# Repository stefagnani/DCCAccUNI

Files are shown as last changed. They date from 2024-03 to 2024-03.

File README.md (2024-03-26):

# DCCAccUNI
Decoder DCC accessori universale. Più versioni basati su hardware di base simile per più funzioni

DECODER ACCESSORI UNIVERSALE

Basato su Software e hardware di MERG
https://www.merg.org.uk/resources/dcc_download

Il presente progetto illustra la realizzazione di un decoder DCC accesori per pilotare in alternativa 4 motori lenti (tipo Tortoise Conrad, o KATO)  4 motori elettromeganertici oppure otto luci generiche per illuminazione o segnali.

Basato sul software originale di MERG versione ACC5, permette un funzionamento toggle standard come da specifiche DCC, ovvero un unico indirizzo pilota 4 coppie di comandi (due per scambio), oppure può essere configurato per operare singolarmente ogni uscita.

Il progetto comprende N Assy (versioni hardware) delle schede in funzione del tipo di accessori da pilotare. Ad oggi sono previste tre tipologie di Assy:

ASSY #260324             Hardware per pilotare 4 motori elettromagnetici
ASSY#XXXXX		Hardware per pilotare segnali 
ASSY#XXXXX		Harware per pilotare motori lenti di tpo Totroise, KATO ecc.

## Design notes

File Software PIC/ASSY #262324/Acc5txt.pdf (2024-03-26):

MERG DCC accessory decoder – Firmware version 5 (ACC5)

The firmware version (ACC4) runs either the Pulse decoder (with inbuilt CDU) or the ‘steady state’ decoder with DC outputs. It is compatible with both the MERG accessory encoder and commercial systems like Lenz. However, both of these assume that the decoder will be used to drive point motors with the outputs operating in pairs. Hence it is not possible to activate the 8 outputs individually as either one side or the other of a ‘pair’ is always active. Also, Lenz systems do not send ‘deactivate’ commands so an output cannot be turned off and it is assumed that activating one output of a pair will automatically turn off the other side. This must be a property of the decoder and ACC4 had the ‘toggle’ mode introduced for this purpose. (The MERG encoder does send ‘deactivate’ commands).

From its early stages, the MERG accessory decoders had the capability to operate all 8 outputs independently but this could not be achieved with command stations assuming ‘paired’ operation.

ACC5 now has an option which allows a single decoder board to act as two separate decoders. In this ‘dual’ mode, outputs 1 to 4 are controlled by one decoder address and outputs 5 to 8 are controlled by a different address. This enables a single decoder board to have all 8 outputs individually controlled by systems that assume paired operation. Activating side ‘b’ of an output will turn that output on. Activating side ‘a’ of that output will turn it off so each decoder ‘address’ works 4 outputs.

For ACC5, an activate to point 1 (001) will turn output 1 on and an activate to point 0 (000) will turn output 1 off. When used with the MERG encoder, this means the output is on when the matrix switch is open and off when the switch is closed. This arrangement was to maintain Lenz compatibility where a ‘+’ will turn output 1 on and a ‘-‘ will turn it off. With the MERG encoder, 8 individual on/off switches will control the 8 outputs of a single decoder board.

The main purpose of this arrangement is for light or signal operation. The ‘steady state’
MERG decoder board has outputs suited for 12v bulbs or LEDs (resistors on the decoder board). However, the same board could drive 8 points using the Servo4 drivers as these only need an on / off input.

Method of operation

ACC5 can work in either single or dual mode dependent on the setting of bit 7 (the MSB) of CV545 (CV33). As this cannot be set using ‘register’ mode programming, it requires a programmer capable of accessing CV545 or CV33. Either page mode or direct mode are accepted.

To use as ACC4 (single mode) set CV545, bit 7 off. CV545 also contains the ‘toggle’ bits for Lenz system operation. To use in dual mode, set bit 7 of CV545. In this mode, the toggle bits are ignored.

To set the addresses.

Set CV545 bit 7 off. Then program the decoder as usual with address data at CV513 and CV521. CV513 (CV1) contains the low 6 bits of the address. (0 to 63) and CV521 (CV9) contains the high three bits (0 to 7). When in dual mode, this address controls outputs 1 to 4. CV514 (CV2) should be left at 255 so all outputs are active and CVs 515 to 518 set the on time of the outputs. Note, with the present code, CV515 sets the time for outputs 1 and 2, CV516 for 3 and 4 etc. irrespective of mode. This may be modified in future so all 8 outputs can have different times. When operating lights or signals it will be normal to set the timing CVs to 0 so the output is continuous.

Now set CV545 bit 7 to 1. Repeat the address programming for the decoder that will control outputs 5 to 8. Obviously this second address should be different from the first but it doesn’t have to be consecutive and can be higher or lower than the first address.

The decoder is now set up for dual mode. Reading the CVs in this mode will return the values for the second address. You will need to clear CV545 bit 7 to 0 in order to read the CVs for the first address. Clearing this bit also places the decoder in the conventional ‘single’ mode which would be used for points or other applications requiring paired outputs.

The following alternative CV's and register addresses are supported.
NMRA CV | Alt CV Register
CV513 | CV1 | R1 (Address low 6 bits))
CV514 | CV2 | (not available in register mode)
CV515 | CV3 | R2 (F1 on time)
CV516 | CV4 | R3 (F2 on time)
CV517 | CV5 | R4 (F3 on time)
CV518 | CV6 | R5 (F4 on time)
R6 (Page register)
CV519 | CV7 | R7 (version)
CV520 | CV8 | R8 (manufacturer)
CV521 | CV9 | Address high 3 bits (not available in register mode)
CV541 | CV29 Configuration (not available in register mode)
CV545 | CV33 Sets toggle function for Lenz compatibility and dual mode option.
Not available in register mode

No other CVs are supported.

CV545 (CV33) | bit 0 | sets toggle mode for OP1/2
bit 1 | sets toggle mode for OP3/4
bit 2 | sets toggle mode for OP5/6
bit 3 | sets toggle mode for OP7/8
bit 7 | sets dual decoder mode

Note: The toggle is for Lenz compatibility in single decoder mode only. These bits are ignored in dual mode. For compatibility with the MERG encoder, they should be set to 0.

The ACC5 code on the MERG website has the default CVs set for dual mode at decoder addresses 1 and 2.

M P Bolton | ACC5txt | Rev 1 | 04/08/05

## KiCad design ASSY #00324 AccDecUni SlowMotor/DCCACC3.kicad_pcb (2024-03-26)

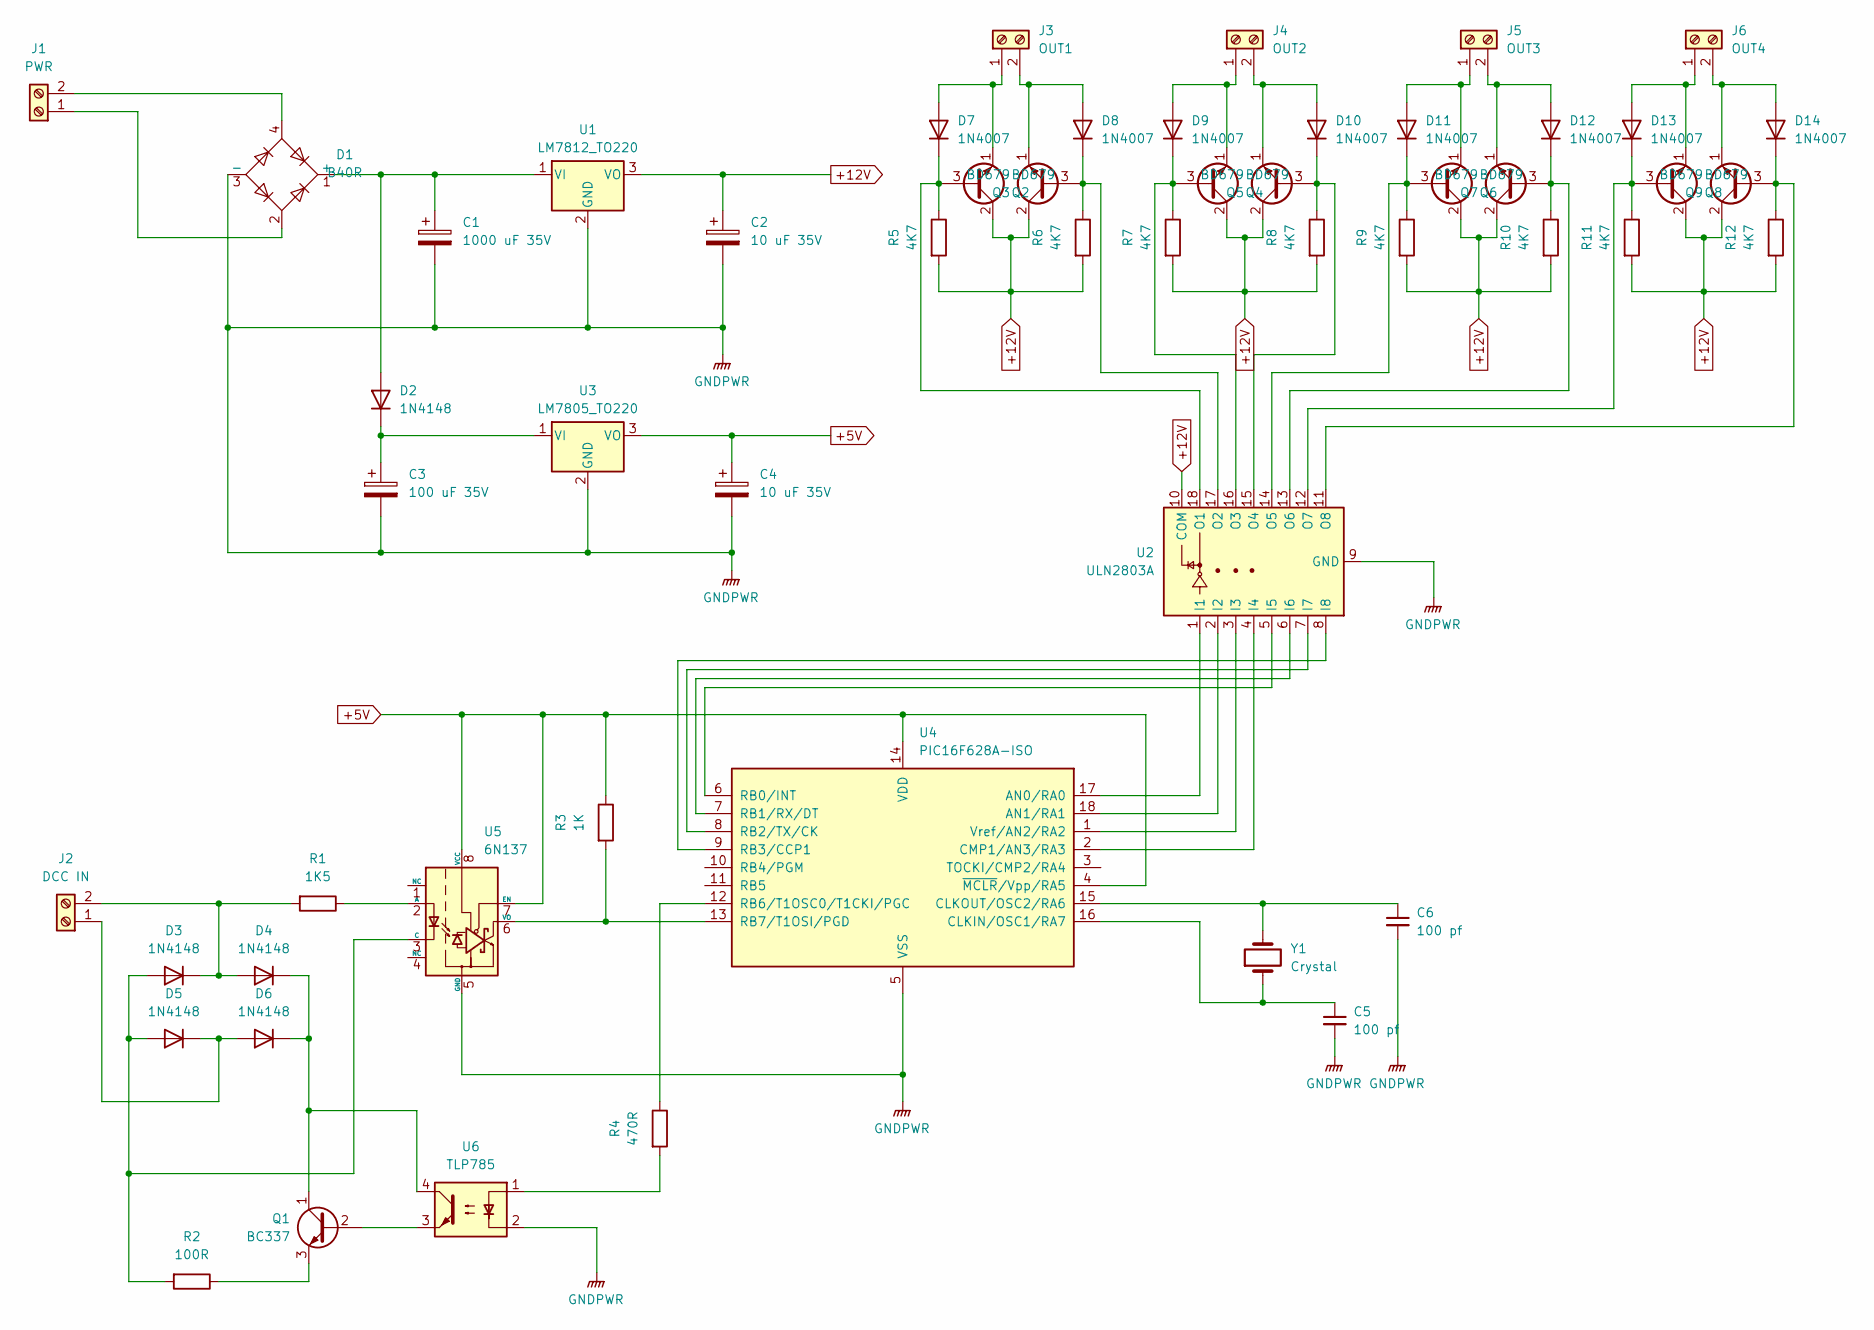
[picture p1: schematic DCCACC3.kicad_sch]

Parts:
C1: 1000 uF 35V; CP_Radial_D16.0mm_P7.50mm
C2, C4: 10 uF 35V; CP_Radial_D5.0mm_P2.50mm
C3: 100 uF 35V; CP_Radial_D10.0mm_P5.00mm
C5, C6: 100 pf; C_Disc_D3.0mm_W2.0mm_P2.50mm
D1: B40R; Diode_Bridge_Round_D9.0mm
D2, D3, D4, D5, D6: 1N4148; D_DO-35_SOD27_P7.62mm_Horizontal
D7, D8, D9, D10, D11, D12, D13, D14: 1N4007; D_DO-41_SOD81_P10.16mm_Horizontal
J1: PWR; mkds_1,5-2
J2: DCC IN; mkds_1,5-2
J3: OUT1; mkds_1,5-2
J4: OUT2; mkds_1,5-2
J5: OUT3; mkds_1,5-2
J6: OUT4; mkds_1,5-2
Q1: BC337; TO-92_Inline
Q2, Q3, Q4, Q5, Q6, Q7, Q8, Q9: BD679; TO-126-3_Vertical
R1: 1K5; R_Axial_DIN0207_L6.3mm_D2.5mm_P7.62mm_Horizontal
R2: 100R; R_Axial_DIN0207_L6.3mm_D2.5mm_P7.62mm_Horizontal
R3: 1K; R_Axial_DIN0207_L6.3mm_D2.5mm_P7.62mm_Horizontal
R4: 470R; R_Axial_DIN0207_L6.3mm_D2.5mm_P7.62mm_Horizontal
R5, R6, R7, R8, R9, R10, R11, R12: 4K7; R_Axial_DIN0207_L6.3mm_D2.5mm_P7.62mm_Horizontal
U1: LM7812_TO220; TO-220-3_Vertical
U2: ULN2803A; DIP-18_W7.62mm
U3: LM7805_TO220; TO-220-3_Vertical
U4: PIC16F628A-ISO; DIP-18_W7.62mm
U5: 6N137; DIP-8_W7.62mm
U6: TLP785; DIP-4_W7.62mm
Y1: Crystal; Crystal_HC18-U_Vertical

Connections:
+5V: C4.1, R3.1, U3.3 (VO), U4.4 (~MCLR/Vpp/RA5), U4.14 (VDD), U5.7 (EN), U5.8 (VCC)
+12V: C2.1, Q2.2 (C), Q3.2 (C), Q4.2 (C), Q5.2 (C), Q6.2 (C), Q7.2 (C), Q8.2 (C), Q9.2 (C), R5.2, R6.2, R7.2, R8.2, R9.2, R10.2, R11.2, R12.2, U1.3 (VO), U2.10 (COM)
GNDPWR: C1.2, C2.2, C3.2, C4.2, C5.2, C6.2, D1.3 (-), U1.2 (GND), U2.9 (GND), U3.2 (GND), U4.5 (VSS), U5.5 (GND), U6.2
unnamed: C1.1, D1.1 (+), D2.2 (A), U1.1 (VI)
unnamed: C3.1, D2.1 (K), U3.1 (VI)
unnamed: D3.2 (A), D5.2 (A), R2.2, U5.3 (C)
unnamed: D3.1 (K), D4.2 (A), J2.2, R1.2
unnamed: D4.1 (K), D6.1 (K), Q1.1 (C), U6.4
unnamed: D5.1 (K), D6.2 (A), J2.1
unnamed: D7.2 (A), J3.1, Q2.1 (E)
unnamed: D7.1 (K), Q2.3 (B), R5.1, U2.18 (O1)
unnamed: D8.2 (A), J3.2, Q3.1 (E)
unnamed: D8.1 (K), Q3.3 (B), R6.1, U2.17 (O2)
unnamed: D9.2 (A), J4.1, Q4.1 (E)
unnamed: D9.1 (K), Q4.3 (B), R7.1, U2.16 (O3)
unnamed: D10.2 (A), J4.2, Q5.1 (E)
unnamed: D10.1 (K), Q5.3 (B), R8.1, U2.15 (O4)
unnamed: D11.2 (A), J5.1, Q6.1 (E)
unnamed: D11.1 (K), Q6.3 (B), R9.1, U2.14 (O5)
unnamed: D12.2 (A), J5.2, Q7.1 (E)
unnamed: D12.1 (K), Q7.3 (B), R10.1, U2.13 (O6)
unnamed: D13.2 (A), J6.1, Q8.1 (E)
unnamed: D13.1 (K), Q8.3 (B), R11.1, U2.12 (O7)
unnamed: D14.2 (A), J6.2, Q9.1 (E)
unnamed: D14.1 (K), Q9.3 (B), R12.1, U2.11 (O8)
unnamed: D1.2, J1.1
unnamed: D1.4, J1.2
unnamed: Q1.2 (B), U6.3
unnamed: Q1.3 (E), R2.1
unnamed: R4.2, U6.1
unnamed: U2.1 (I1), U4.17 (AN0/RA0)
unnamed: U2.2 (I2), U4.18 (AN1/RA1)
unnamed: U2.3 (I3), U4.1 (Vref/AN2/RA2)
unnamed: U2.4 (I4), U4.2 (CMP1/AN3/RA3)
unnamed: U2.5 (I5), U4.6 (RB0/INT)
unnamed: U2.6 (I6), U4.7 (RB1/RX/DT)
unnamed: U2.7 (I7), U4.8 (RB2/TX/CK)
unnamed: U2.8 (I8), U4.9 (RB3/CCP1)
unnamed: C5.1, U4.16 (CLKIN/OSC1/RA7), Y1.1
unnamed: C6.1, U4.15 (CLKOUT/OSC2/RA6), Y1.2
unnamed: R4.1, U4.12 (RB6/T1OSC0/T1CKI/PGC)
unnamed: R3.2, U4.13 (RB7/T1OSI/PGD), U5.6 (VO)
unnamed: R1.1, U5.2 (A)

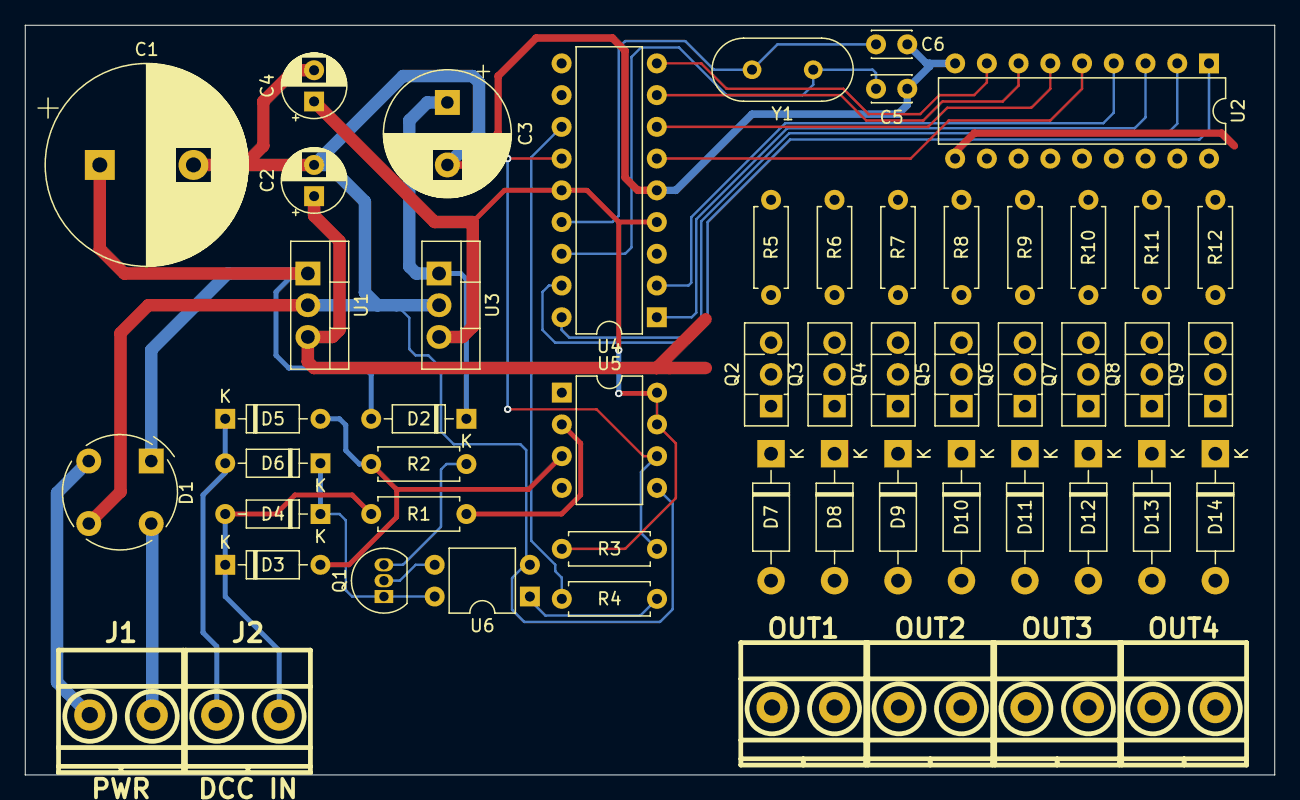
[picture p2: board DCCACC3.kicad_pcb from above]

Board: 2 copper layers, 100.0 x 60.0 mm, 54 parts (0 on the bottom side), 43 nets.

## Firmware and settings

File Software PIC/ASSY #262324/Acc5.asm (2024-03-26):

;*******************************************************************************
;
;	Acc5
;	
;	This is a new version based on Acc4 so that 8 individual outputs can be 
;	controlled as two blocks of 4 at separate addresses. This allows either
;	the MERG encoder or other commercial controllers which expect outputs to
;	only work in pairs to work individual outputs. In this mode, an activate to
;	the first of a pair turns that output on. An activate to the other in a pair
;	turns the first output off. Main purpose is to allow 8 signals / lights from
;	one decoder. Also will operate 8 points via two  MERG Servo4 boards.
;
;	There are two completely separate blocks of CVs so it is effectively two 
;	decoders in one. This dual mode is set by bit 7 of CV545 (CV33)
;
;	If this bit is 0, the decoder operates as a standard Acc4.
;	Tested with MERG encoder in mode 1. 11/05/05. Seems OK
;	Not tested with a Lenz system.
;	Acc5 modified for Lenz system  30/05/05 to reverse the output pairs
;
;	Note:  Default setting is dual mode.
 
;	Accessory decoder based on original loco decoder program by D Probst 
;	to whom full acknowledgement is made.
;
;	First modified for accessory control by Mike Bolton  2nd Dec 1998
;	Revised 25/5/02 for 16F628 PIC
;
;	Program is intended to be used with the accessory decoder designs    	
;	DCCACC2B and DCCACC3. The decoder is opto isolated . No power booster is required 
;	but the signals can be taken from the track if desired. 
;	A separate 20v AC power supply is needed.
;	Decoder includes circuitry to drive solenoid
;	point motors using a capacitor discharge technique. 
;
;	
;
;	Schematic, PCB layout and source listing (+ HEX file) available. Contact
;	Mike Bolton at mbolton@fs1.with.man.ac.uk.
;
;	Details of a matching accessory encoders are also available.
;
;	
;This is code for a PIC16F628A . This program will read three, four,
;and five byte packets and supports paged, direct CV or register mode 
;access of CV data. Direct read uses bit mode. Direct write uses both
;byte write or bit manipulation.
;
;
;The decoder follows the NMRA standard for an Accessory Decoder. It controls
;four pairs of outputs with on times set by the CVs in increments of 
;10 millisecs. Range is 10 ms to 2.54 sec.or continuous.
;
;Supports 9 bit addressing. (3 byte packets) at present.

;The processor is configured to operate at 8MHz. 
;When programming,the fuses should be set with HS clock, WDT On.
;

;The following NMRA defined CV's and ranges are supported...

;NMRA  alt
;CV513 (1)  Lower 6 address bits    00h - 3Fh  
;CV514 (2) Auxiliary activation    00h - FFh  Bits 0 to 7.Each bit sets an output.
;					   1 is active, 0 is inactive   
;CV515 F1 function 'on' time   00h - FFh  Time in 10ms steps. 0 is continuous.
;CV516 F2  
;CV517 F3                                        
;CV518 F4
;CV519 Version Number     	00h -FFh   Cannot be changed (same as CV8)
;CV520 Manufacturers ID        00h -FFh   Cannot be changed (same as CV9)
;                
;CV521 Upper 3 bits of		00h -07h
;      	    address     
;CV541 Configuration		Bit 7 = 1  (same as CV29)
;CV545 Mode			Bits 0 to 3 set the toggle mode on output pairs (Lenz compatibility)
;				Bit 7 sets dual mode

; The following alternative CV's and register addresses are supported.
; NMRA CV  Alt CV   Register
; CV513    CV1      R1 (Address)
; CV514    CV2         (not available in register mode)
; CV515    CV3      R2 (F1 on time)
; CV516    CV4      R3 (F2 on time)
; CV517    CV5      R4 (F3 on time)
; CV518    CV6      R5 (F4 on time)
;                   R6 (Page register)
; CV519    CV7      R7 (version)
; CV520    CV8      R8 (manufacturer)
; CV521    CV9         (not available in register mode)
; CV541    CV29        (not available in register mode)
; CV545	   CV33		(sets toggle function for Lenz compatibility)
; 
;	No other CVs are supported.

        processor       16F628A
	include		"p16f628A.inc"
	__CONFIG	h'3F66' ; PUTimer on, WDT on, HS clock, BOD on

				; 8 Mhz Crystal

;Variable definition - I/O Port assignments

;F1a  	equ    	PORTA,0		;pin 17
;F1b	equ		PORTA,1		;pin 18   
;F2a  	equ     PORTA,2		;pin 1
;F2b  	equ    	PORTA,3		;pin 2
;F3a	equ		PORTB,0		;pin 6
;F3b  	equ     PORTB,1		;pin 7
;F4a  	equ		PORTB,2    	;pin 8
;F4b	equ     PORTB,3		;pin 9              
;ackout	equ		PORTB,6		;pin 12 (acknowledge)
;dat	equ		PORTB,7		;DCC data in














;bit definitions


primary equ    	0     	;primary address match
reset 	equ     1     	;reset packet
brdcst	equ		2		;accessory broadcast
service equ    	3
altadr	equ		4		;alternative primary address (mode 1)
value   equ    	0
byte4   equ    	1     	
byte5   equ    	2 	;not used yet


;registers

	CBLOCK	0x0020

	addcfg    	;address configuration
	confg	
	count   	;counts which output
	CV513a  	;holds CV513 low address bits
	CV521a  	;holds CV521 high address bits
	CV514a		;which outputs to activate
	CV515a		;times for fast access
	CV516a
	CV517a
	CV518a
	CV541a   	;config CV
	CV545a		;toggle CV
 				;alternate decoder CVs
	CV513_2a  	;holds CV513 low address bits
	CV521_2a  	;holds CV521 high address bits
	CV514_2a	;which outputs to activate
	CV515_2a	;times for fast access
	CV516_2a
	CV517_2a
	CV518_2a
	CV541_2a   	;config CV
	
	toggle		;register for Lenz toggle state
	mode		;for single / dual mode 
	endval  
	lastd1  
	lastd2  
	lastd3  
	lastd4  
	action		;4 bits of accessory command
	tick1		;counts 10 millisec intervals
	time1		;on time for output 1 etc.
	time2	
	time3	
	time4	
	time5	
	time6	
	time7	
	time8	

	pagereg 
	m       	;as in Dean Probst's decode
	n       
	state   
	temp    
	arg3	
	arg4	
  
	ENDC

	CBLOCK	0x0071	;for access in any page

	data1   	;first packet byte
	data2   	;second packet byte
	data3   
	data4   
	data5
   	
	ENDC

;Init sets PORTA as all outputs, pin b7 as input and the rest of PORTB as
;outputs and sets the TMR0 counter to divide by 32 (16us at 8MHz clock).
	org	0000
	nop
	goto	Init

Init  bsf	STATUS,RP0	;set to page 1
	movlw	B'00000000'	;port a outputs 
	movwf	TRISA
	movlw	B'10000000'	;port b 7 is data in
	movwf	TRISB
	movlw	B'10000100'	;set OPTION reg RTCC /32
	movwf	OPTION_REG
	bcf		STATUS,RP0
	movlw	B'00000111'	;
	movwf	CMCON		; turn comparators OFF
	clrf    PORTA
    clrf    PORTB
    clrf    INTCON
        
        
    clrf    state
    clrf    m
    clrf    n
    clrf    confg
    clrf	action
	clrf	toggle
	call	refresh		;refresh the CVs
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
